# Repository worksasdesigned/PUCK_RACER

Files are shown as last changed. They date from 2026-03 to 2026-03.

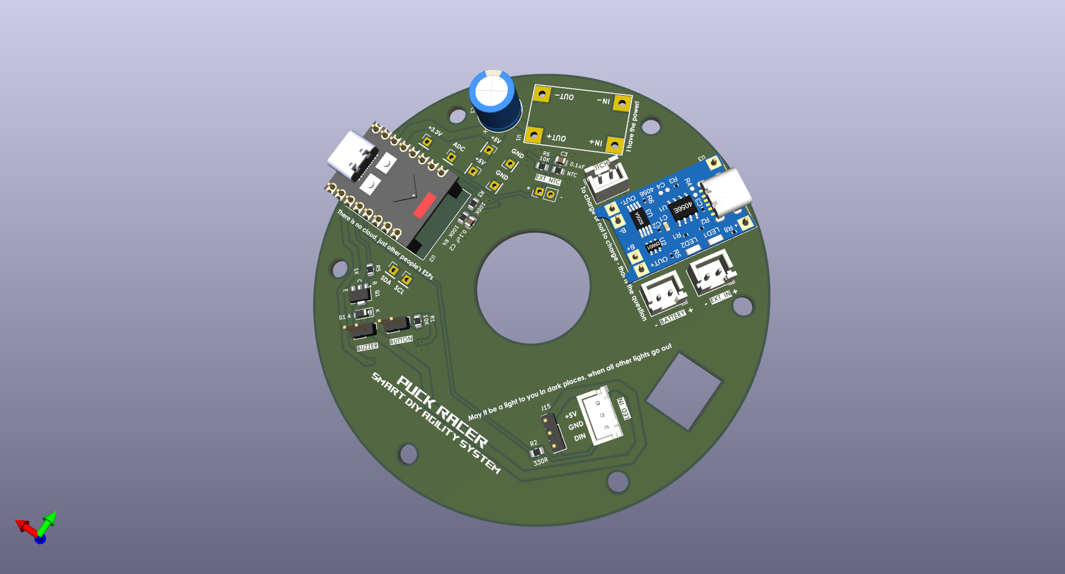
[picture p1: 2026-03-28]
Hardware/PCB Project Outputs/3D Views/Puck Racer_S3.png

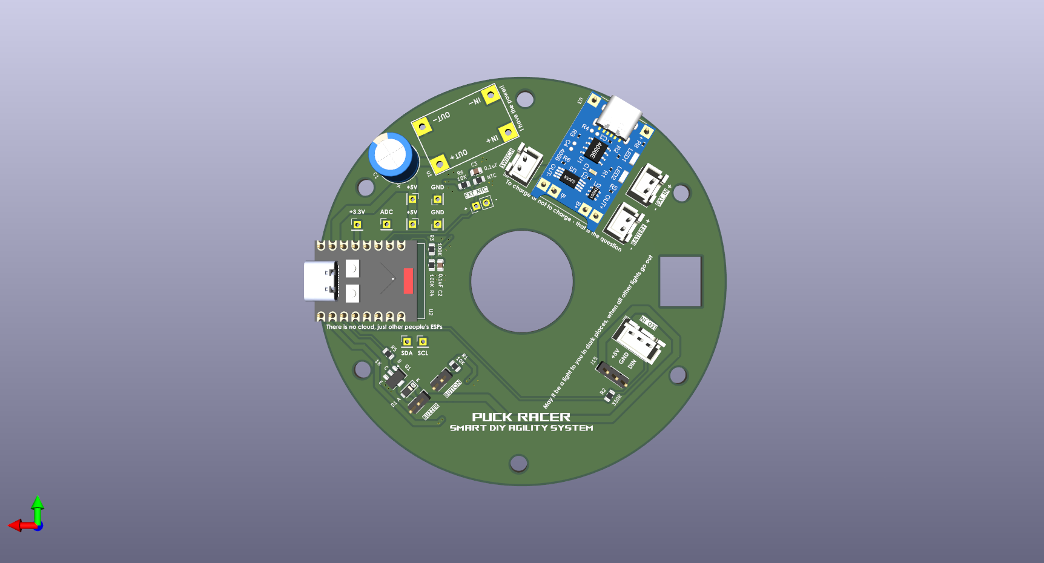
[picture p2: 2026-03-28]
Hardware/PCB Project Outputs/3D Views/Puck Racer_BOTTOM.png

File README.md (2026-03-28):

# Puck Racer 🏃‍♂️💨
**The DIY agility System**

## 📖 The Story: Why this exists
Let's be real for a second: I built this because I was simply too stingy to drop **300-400€** on a commercial reaction light system that consists of only 4 pucks, needs a paid subscription and provides 200 extremely similar games... which can be summerized in 5 different game modes.  
**Puck Racer has now 26 games**. Highly adjustable. Multi-Player, Multi-Group support.  
All options combined easily provide 200+ "games" ;-)  

I also noticed that the PE equipment at my kids' elementary school hasn't really changed in 40 years. It was time for an upgrade.

**Puck Racer** is the answer. It’s perfect for professional training support in sports clubs, spicing up PE lessons in schools, or just being the absolute highlight of the next kids' birthday party.  
I would descibe it as a **blaze**ing**POD** - DIY solution - just on steroids :-)  

**The Trade-off:**
Yes, building 4-10 Pucks and a Coordinator is a bit of a grind. It takes time and patience.

**The Reward:**
You get a fully customizable system where the hardware cost per Puck can be pushed **under 20€**. You do the math. 😉  
Nice side effect: Teach your kids how to solder. Its easy to medium difficulty. My 9 year old twins built 5 pucks by them selfe with very little help.  

---

## 🛠 Hardware
*detailed howto and hardware list will be provided once its worth it*  
ESP32-C3 for pucks   (use the one with external antenna or built a small antenna!)
ESP32-S3 for Coordinator  
WS2812B 35LED ring  
something for 18650 Battery placement + stepup to 5V  
Arcade Button (bigger is better) 60mm  
3D printer for pucks  
Soldering Stuff  
**P A T I E N C E** - printing 10 pucks, soldering 10 times the same stuff and initial flashing needs a good amount of patience.

---

## 💻 Software & Installation

This system relies on a **Coordinator** (ESP32-S3) that acts as the brain and the WiFi Access Point, and multiple **Pucks** (ESP32-C3) that communicate via ESP-NOW.

### 📦 Prerequisites

To compile and flash this project, you need the **Arduino IDE**. Of cause VS Code will also work. 

1.  **ESP32 Board Manager:**
    * Go to *Tools > Board > Boards Manager*.
    * Install **esp32 by Espressif Systems**.
    * **Recommended Version:** `3.0.0` or higher (we need proper S3/C3 support).

2.  **Required Libraries:**
    Install these via the Arduino Library Manager:
    * `FastLED` (for the WS2812B LEDs)
    * `ESPAsyncWebServer from ESPhome project` (for the Coordinator Dashboard)
    * `AsyncTCP from ESPhome project` (dependency for the WebServer)

### 📂 Uploading the Web Interface (IMPORTANT!)

The Coordinator runs a modern Web App stored in the ESP32's internal file system (LittleFS). You **must** upload the files from the `data` folder, otherwise, you'll just see a blank screen.

1.  Download the **Arduino LittleFS Upload Tool**:
    * 👉 [GitHub Link: arduino-littlefs-upload](https://github.com/earlephilhower/arduino-littlefs-upload)
2.  Follow the installation instructions on the repo (copy to `tools` folder).
3.  In Arduino IDE, select the Coordinator board.
4.  Click **Tools > ESP32 LittleFS Data Upload**.

### 📡 Connectivity & OTA Updates

**The Network:**
The Coordinator opens a WiFi Access Point (Default SSID: `PuckRace_Trainer`). Connect your phone or laptop to this network and navigate to `http://192.168.42.1`. No app required, it runs in the browser.  It has no pwassword initially. Your choice to set it up if you deal with kids and their smartphones.

**Wireless Updates (OTA):**
You only need to hook the Pucks up to USB *once* for the initial flash. After that, you're free:
1.  Compile the new Puck firmware (Sketch -> Export Compiled Binary).
2.  Go to the Coordinator Web Interface Settings.
3.  Upload the `.bin` file.
4.  Hit **"Update All Pucks"**. The Coordinator will distribute the update wirelessly to all active Pucks. Magic. ✨

After the real first beta is released il will provide the bin files in case of updates. 

---

## 🎮 The Games

**26 games** across 4 categories. Highly adjustable, multi-player and multi-group support.

| Focus | Icon |
|---|---|
| Hand-eye coordination, fast stimulus processing | ⚡ Reaction |
| Rapid direction changes, sprints, footwork | 🏃‍♂️ Agility |
| Cardiovascular load and pacing | 🫀 Endurance |
| Memory, timing, stress resistance | 🧠 Cognition |
| Teambuilding and motivation | 🤪 Fun |
| Practical tools for coaches and teachers | 🛠️ Utility |

---

### ⚡🏃‍♂️ Agility & Reaction

| Game | Players | Pucks | Focus | Highlights |
|---|---|---|---|---|
| 🎯 **Hunt! (Color Hunt)** | 1–10 | 3–20 | ⚡ 🏃‍♂️ 🧠 | Dynamic queues, adjustable timeout, 1-sec warning |
| ⚡ **React 2-Player** | 2–10 (pairs) | 3–10/group | ⚡ 🧠 | Configurable colors, fake stimuli for confusion |
| 🎯 **Target Touch** | 1–5 groups | 2–10/group | ⚡ 🛠️ | Sequence or random mode, rest time control |
| 🏃‍♂️ **Agility T-Test** | 1–2 groups | 4/group | 🏃‍♂️ | Standard T-test layout, mandatory touch mode |
| 🐱 **Cat Reflex** | 1–11 | 1/player + 1 center | ⚡ | Highlander mode, Color Chaos (false-start training) |
| ⚡🎯 **Catch the light Pro** | 1 | 3–20 | ⚡ 🧠 | Adaptive speed, fake colors, per-puck reaction analysis |

---

### 🫀 Endurance & Pacing

| Game | Players | Pucks | Focus | Highlights |
|---|---|---|---|---|
| ⏱️ **The Pacemaker** | Groups | 4–20 | 🫀 🧠 | Exact pace (min/km), circle or shuttle, live distance |
| 🏃‍♂️ **Luc Léger (Beep Test)** | 1–10 | 2/player | 🫀 | Official VO₂max tables, false start detection |
| 🏃‍♂️ **Shuttle Run** | 1–5 | 2/player | 🏃‍♂️ 🫀 | Winner detection, false start detection |
| 🧟 **Zombie Escape** | 1–10 groups | 2/group | 🫀 🧠 🤪 | Auto time reduction, sudden death mode |
| 🏎️ **Pit Stop** | 1–10 groups | 1-2/group | 🫀 | Making a break. Defined PitStops. Pitlane mode. |

---

### 🧠🤪 Cognition & Fun

| Game | Players | Pucks | Focus | Highlights |
|---|---|---|---|---|
| 🔴 **Simon Says** | 1–3 groups | 2–10/group | 🧠 | Adjustable speed, color-blind palette |
| 🏃‍♂️ **Simon Runs** | 1–3 groups | 1 display + inputs | 🧠 🏃‍♂️ | Central display mode, disqualification management |
| 💣 **Bomb Squad** | 1–10 | 1/player | 🧠 🤪 | Adjustable tolerance, group sync mode, explosion feedback |
| 🚦 **Red Light, Green Light** | 1–10 groups | 1–20 | 🤪 ⚡ | Grace period, coach override |
| 🎩 **The Sorting Hat** | 2–100 | 1–3 | 🛠️ 🤪 | Balanced assignment, live rebalance |
| 🧠 **Memory Sprint** | 1+ | 4–20 (pairs) | 🧠 🏃‍♂️ | Blind search mode, auto-restart, live error tracking |
| ⚔️ **Domination (Turf War)** | 2 teams/arena | 2+/arena | 🏃‍♂️ 🫀 | 1-click vs 2-click capture, dual-arena support |
| ❌⭕ **Tactical TicTacToe** | 1–3 groups | 4 / 6 / 7 / 10 | 🧠 | Hard-Mode, grid auto-adapts to puck count |
| 🪑 **Musical Chairs** | 2–13 | Player count −1 | 🤪 🏃‍♂️ | Custom MP3 upload, dynamic round elimination |

---

### 🛠️ Measurement Tools & Utilities

| Game | Players | Focus | Highlights |
|---|---|---|---|
| ⏱️ **Stopwatch** | 1–10 | 🛠️ | Split/lap times, central or individual start, Hold-to-Start |
| ⏳ **Simple Timer** | 1–10 | 🛠️ | Visual countdown fill, live +/− time adjustment per player |
| 🔢 **Simple Counter** | 1–10 | 🛠️ | Tap-to-count, time limit, debounce filter |
| ⬇️ **Simple Countdown** | 1–10 | 🛠️ | Count down from N, stop-on-winner option |
| 🥵 **TABATA Controller** | Unlimited | 🛠️ 🫀 | Synced progress bars, work/rest phases, configurable sound |
| ▶️ **Display Mode** | — | 🛠️ | Manual/sync/random light control for events |

---

### 👥 Player & Training Manager

| Tool | Description |
|---|---|
| 👥 **Player Manager** | Manage teams and class lists. Upload/backup CSV. Create named groups for quick name assignment. |
| 📋 **Training Manager** | Define training sequences with up to 3 games and pre-set all parameters. Jump between games without touching the setup screens. |

---

## Technical Updates:  

**V2.88.2**  
    - iOS meta Tags added  
    - App Icon added  
    - Check that only 1 device is connected via WiFi  

**V2.89.7**   
    - Simple Statistics added for players maintained in Playermanager  
    - CatReflexes (avarage reaction time)  
    - BombSquad (avarage reaction time)  
    - Shuttle run (time) assuming trainer always uses same distance, else its just a tracking of usage  
    - Countdown (time and clicks) tracking of usage - Fix of copy&paste error in game_simplecounter_setup.html      
**V2.89.13**  
    - statistics for all relevant games finished  
        - Whac-A-Mole  
        - Pacemaker  
        - React2Player  
        - T-Test  
        - Beep Test  
        - Catch the light (incl. System record)  
    - Player manager with extended Export and Import incl. highscores and statistics   
    - Minor bugfixes in some games (Player-List added, minor layout changes)  
        - fix for Whac-A-Mole color picker  
**V2.89.15**   
    - Tutorial adjusted  

**V2.90.12**   
    - RSSI fixed  
    - 12 games small fixes (puck colo) fixed  
    - snall enhancements in various games after Beta Test 1  

**V2.91.1**   
    - new game: Pit Stop  
    - Red Light Green Light small adjustments and fixes  

**V2.92.3**   
    - rename a game to catch the light  
    - Cat Reflex Highlander Mode adjusted  

**V2.93.0**   
    - Bidirectional heartbeat puck firmware 81  

**V2.94.2**   
    - UI 2.0 new design    

**V2.96.1**   
    - Battery Management and auto Power Saving Mode   
    - Toast Message "low Battery level", "shutdown Puck due to critical battery level"   
    - Puck shutdown (deepsleep) at low Battery level (safety)   
    - Puck blocks reboot under 3,6V Battery level (safety)  
    - Max LED Power Consumption reduced to 1.2A (should only effect white @35LEDs) (safety)   
    - Hardware Watchdog implemented (Puck restarts after 3s off non-reactivity)   

**V2.97.1**   
    - Anti-cache links added (Core version behind urls)   
    - _setup.html remembers settings, when navigation back from _run to _names  to _setup.html    

**V2.98.0**   
    - Gerber and PCB files addes   
    - temperature control, warning and local alarm added     

--- 

## 🤝 Contributing
Found a bug? Have a game idea? Feel free to open an issue or submit a pull request. Let's make school sports digital (and affordable)!  
**Licence:** Use it, change it, DO NOT SELL it.  see License.txt

*Project by WorksAsDesigned*

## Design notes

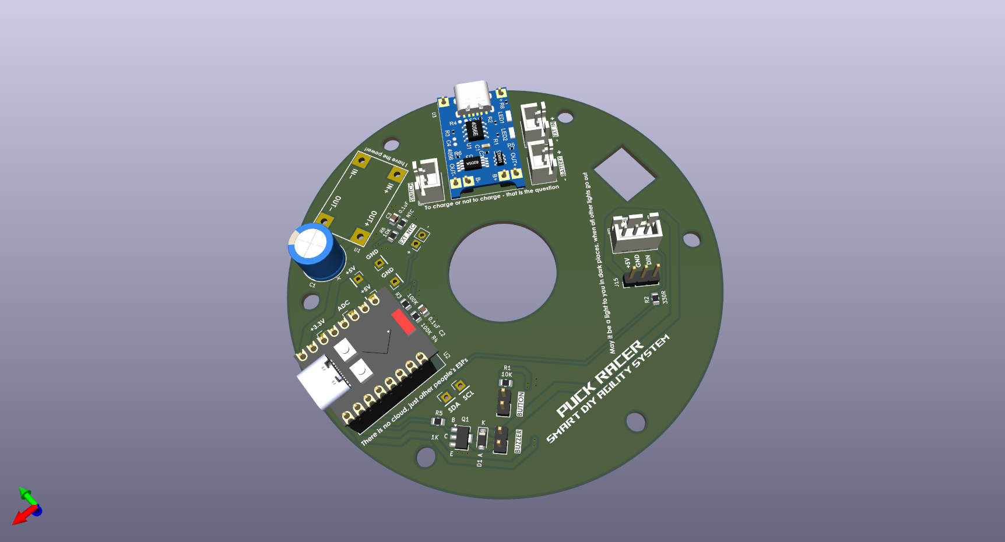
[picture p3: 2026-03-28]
Hardware/PCB Project Outputs/3D Views/Puck Racer_S1.png

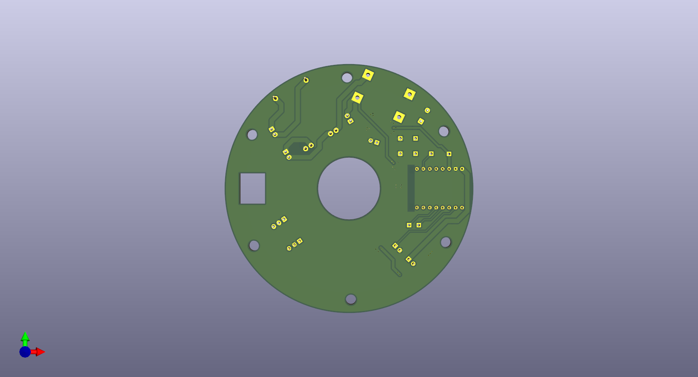
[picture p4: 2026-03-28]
Hardware/PCB Project Outputs/3D Views/Puck Racer_TOP.png

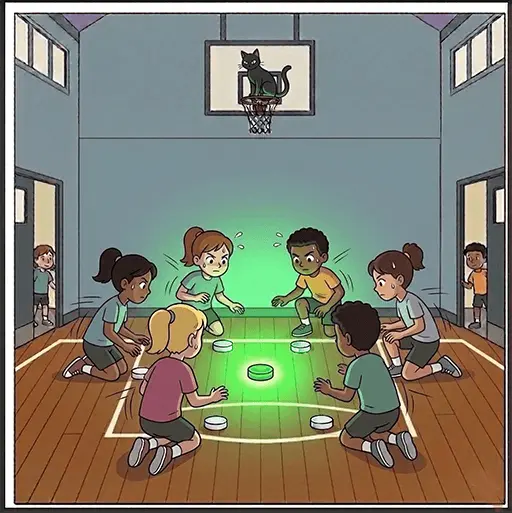
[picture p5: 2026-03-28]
webseite/pictures/img_catreflex.webp

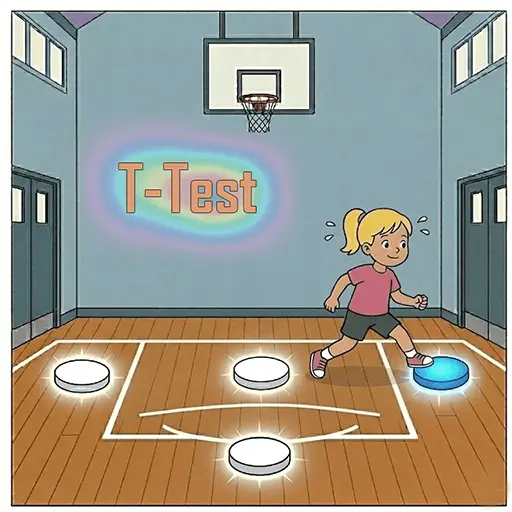
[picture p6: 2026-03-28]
webseite/pictures/img_ttest.webp

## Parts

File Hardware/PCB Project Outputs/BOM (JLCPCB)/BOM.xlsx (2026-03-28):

Comment | Designator | Footprint | JLCPCB Part #
100nF | C2, C3 | Capacitor_SMD:C_0805_2012Metric | C28233
1N4148W | D1 | Diode_SMD:D_SOD-123 | C2099
B2B-XH-A(LF)(SN) | J6, J7, J10 | Connector_JST:JST_XH_B2B-XH-A_1x02_P2.50mm_Vertical | C158012
B3B-XH-A(LF)(SN) | J12 | Connector_JST:JST_XH_B3B-XH-A_1x03_P2.50mm_Vertical | C144394
2N2222AU | Q1 | Package_TO_SOT_SMD:SOT-89-3 | C21714170
10K | R1, R6 | Resistor_SMD:R_0805_2012Metric | C17414
330 | R2 | Resistor_SMD:R_0805_2012Metric | C17630
100K | R3, R4 | Resistor_SMD:R_0805_2012Metric | C25611
1K | R5 | Resistor_SMD:R_0805_2012Metric | C17513
10K NTC | TH1 | Resistor_SMD:R_0805_2012Metric | C95968

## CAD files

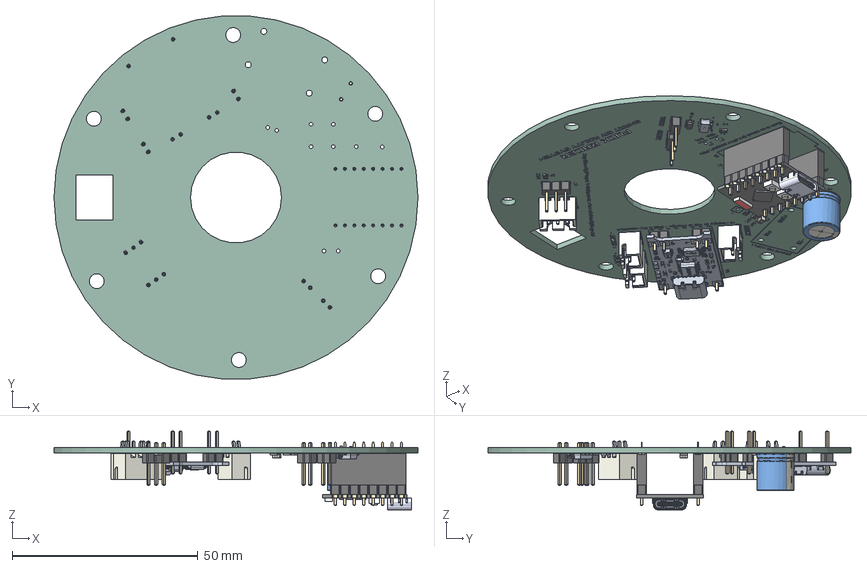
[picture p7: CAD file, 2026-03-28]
Hardware/PCB Project Outputs/STEP/Puck Racer.step
98.0 x 97.7 x 21.2 mm
PinHeader_1x02_P2.54mm_Vertical x 2
R_0805_2012Metric x 7
C_0805_2012Metric x 2
Board c3mini
USB C
components (other)^ESP32-C3 SuperMini
PinHeader_1x08_P2.54mm_Vertical x 2
PinSocket_1x08_P2.54mm_Vertical x 2
JST_XH_B2B-XH-A_1x02_P2.50mm_Vertical x 3
PinHeader_1x01_P2.54mm_Vertical x 6
Puck Racer 1.19.1
Puck Racer 1.19.2
CP_Radial_D10.0mm_P5.00mm
D_SOD-123
JST_XH_B3B-XH-A_1x03_P2.50mm_Vertical
Puck Racer 1.23.1
PinHeader_1x03_P2.54mm_Vertical
Puck Racer_silkscreen
Puck Racer_PCB

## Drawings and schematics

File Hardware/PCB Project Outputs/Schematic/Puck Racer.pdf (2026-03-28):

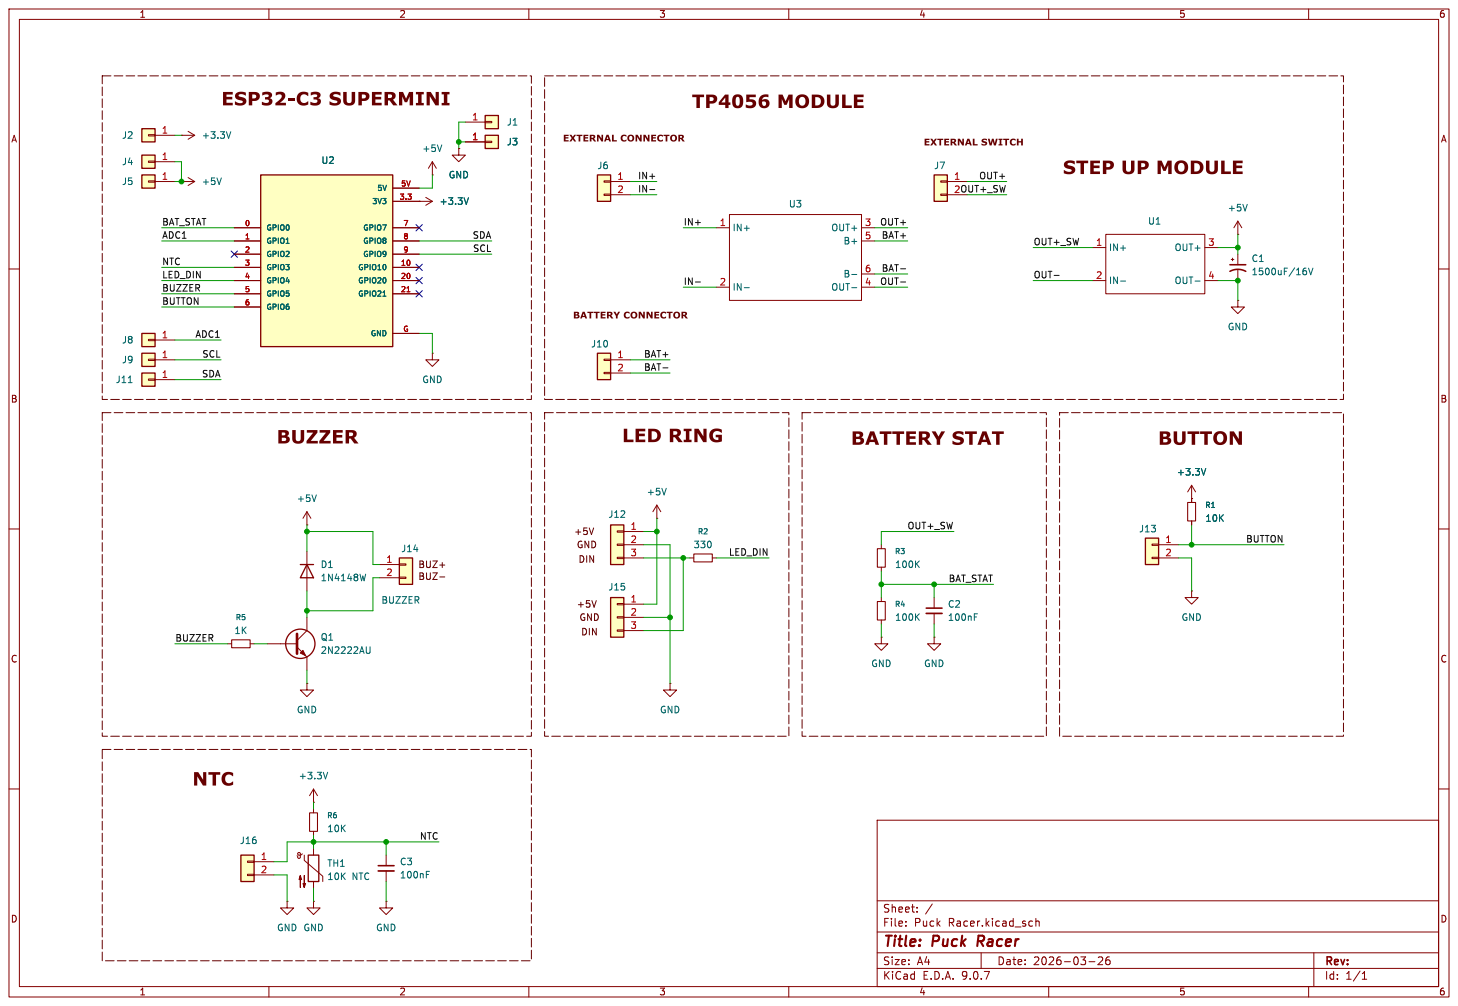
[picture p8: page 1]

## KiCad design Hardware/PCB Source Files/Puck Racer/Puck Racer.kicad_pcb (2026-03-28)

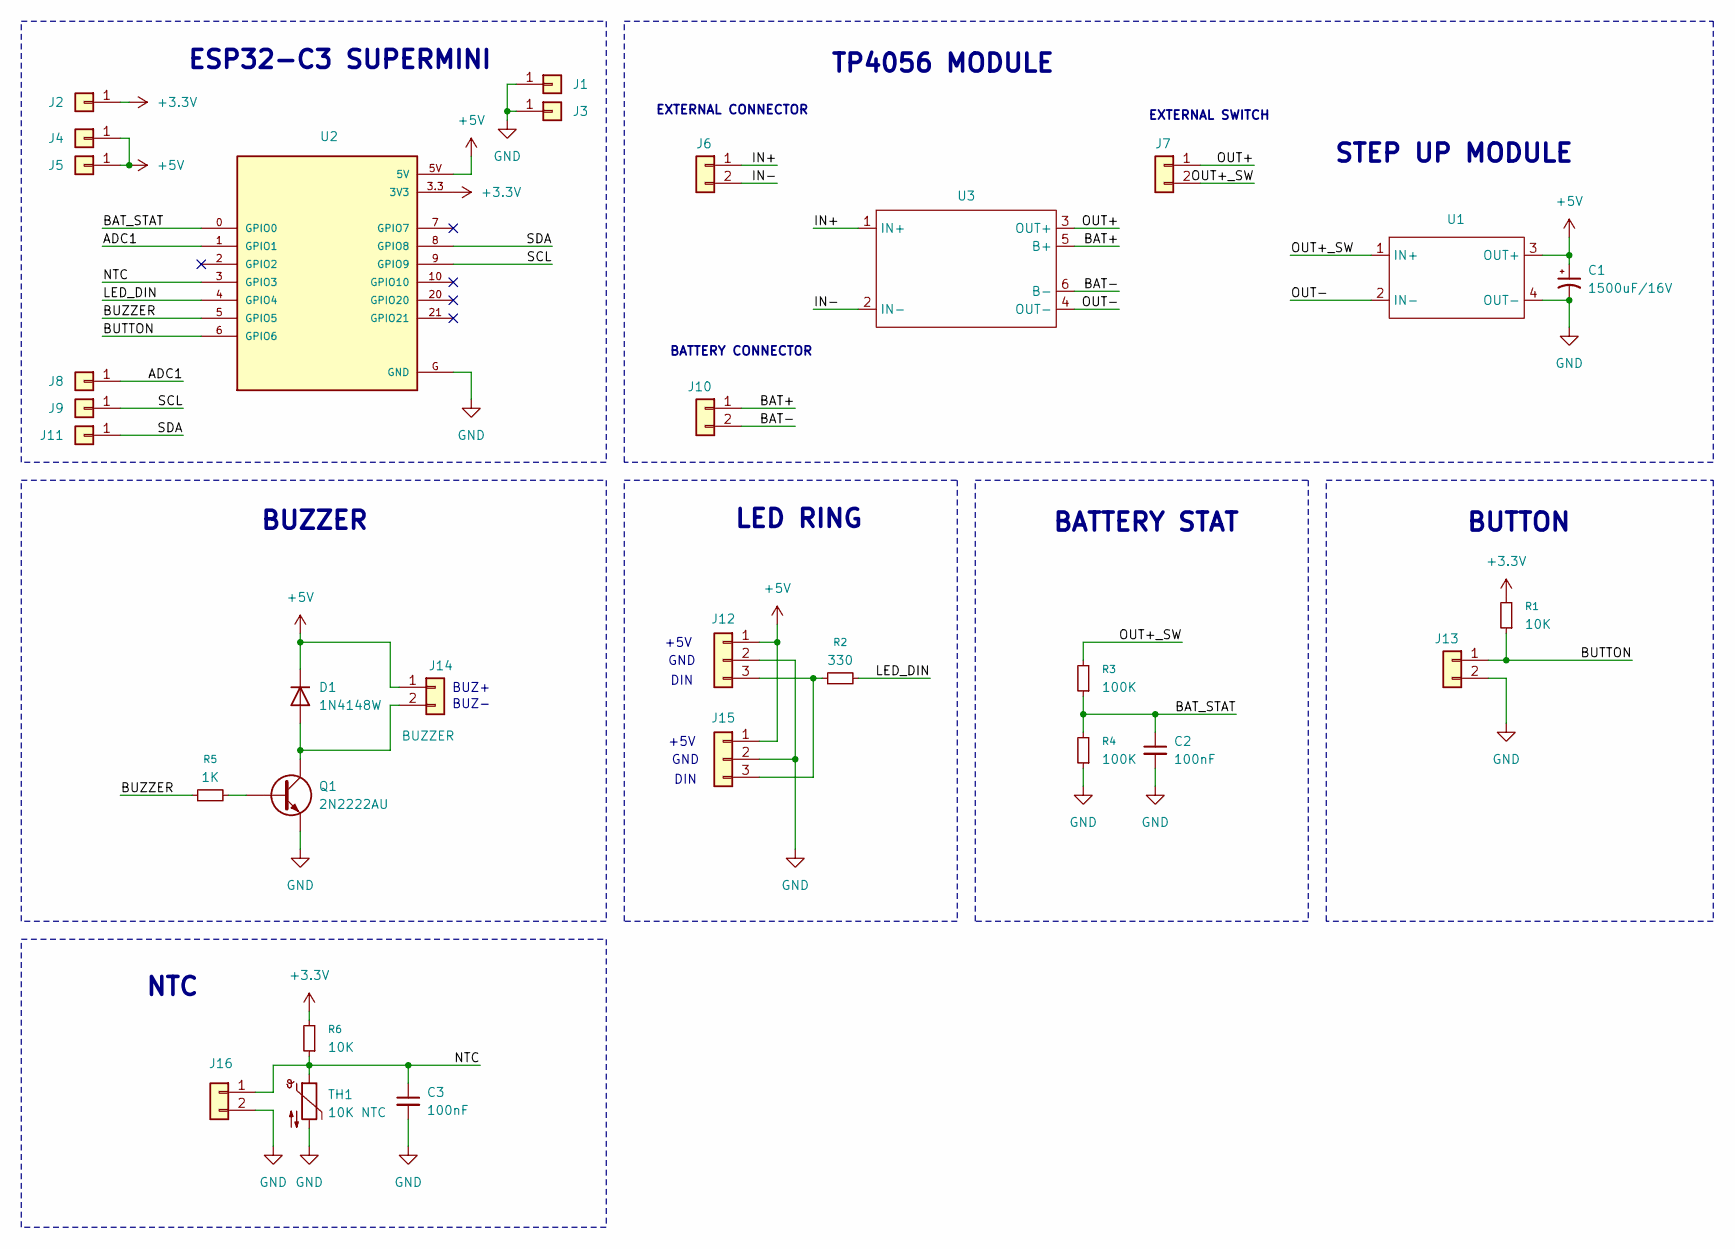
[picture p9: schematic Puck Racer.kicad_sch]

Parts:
C1: 1500uF/16V; CP_Radial_D10.0mm_P5.00mm
C2, C3: 100nF; C_0805_2012Metric; JLCPCB Part # C28233
D1: 1N4148W; D_SOD-123; JLCPCB Part # C2099
J1, J2, J3, J4, J5, J8, J9, J11: Conn_01x01; PinHeader_1x01_P2.54mm_Vertical
J6, J7, J10: B2B-XH-A(LF)(SN); JST_XH_B2B-XH-A_1x02_P2.50mm_Vertical; JLCPCB Part # C158012
J12: B3B-XH-A(LF)(SN); JST_XH_B3B-XH-A_1x03_P2.50mm_Vertical; JLCPCB Part # C144394
J13, J16: BUTTON1; PinHeader_1x02_P2.54mm_Vertical
J14: BUZZER; PinHeader_1x02_P2.54mm_Vertical
J15: LED; PinHeader_1x03_P2.54mm_Vertical
Q1: 2N2222AU; SOT-89-3; JLCPCB Part # C21714170
R1, R6: 10K; R_0805_2012Metric; JLCPCB Part # C17414
R2: 330; R_0805_2012Metric; JLCPCB Part # C17630
R3, R4: 100K; R_0805_2012Metric; JLCPCB Part # C25611
R5: 1K; R_0805_2012Metric; JLCPCB Part # C17513
TH1: 10K NTC; R_0805_2012Metric; JLCPCB Part # C95968
U1: Step Up Power Module
U2: ESP32-C3_SUPERMINI_TH; MODULE_ESP32-C3_SUPERMINI_TH
U3: TP4056 Module

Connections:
+3.3V: J2.1, R1.2, R6.2, U2.3.3 (3V3)
+5V: C1.1, D1.1 (K), J4.1, J5.1, J12.1, J14.1, J15.1, U1.3 (OUT+), U2.5V
/ADC1: J8.1, U2.1 (GPIO1)
/BAT+: J10.1, U3.5 (B+)
/BAT-: J10.2, U3.6 (B-)
/BAT_STAT: C2.1, R3.1, R4.2, U2.0 (GPIO0)
/BUTTON: J13.1, R1.1, U2.6 (GPIO6)
/BUZZER: R5.1, U2.5 (GPIO5)
/IN+: J6.1, U3.1 (IN+)
/IN-: J6.2, U3.2 (IN-)
/LED_DIN: R2.2, U2.4 (GPIO4)
/NTC: C3.1, J16.1, R6.1, TH1.1, U2.3 (GPIO3)
/OUT+: J7.1, U3.3 (OUT+)
/OUT+_SW: J7.2, R3.2, U1.1 (IN+)
/OUT-: U1.2 (IN-), U3.4 (OUT-)
/SCL: J9.1, U2.9 (GPIO9)
/SDA: J11.1, U2.8 (GPIO8)
GND: C1.2, C2.2, C3.2, J1.1, J3.1, J12.2, J13.2, J15.2, J16.2, Q1.3 (E), R4.1, TH1.2, U1.4 (OUT-), U2.G (GND)
unnamed: D1.2 (A), J14.2, Q1.2 (C)
unnamed: J12.3, J15.3, R2.1
unnamed: Q1.1 (B), R5.2

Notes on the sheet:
GND
BUTTON
STEP UP MODULE
BUZZER
DIN
NTC
LED RING
+5V
BUZ+
EXTERNAL CONNECTOR
EXTERNAL SWITCH
BATTERY STAT
BUZ-
TP4056 MODULE
BATTERY CONNECTOR
ESP32-C3 SUPERMINI

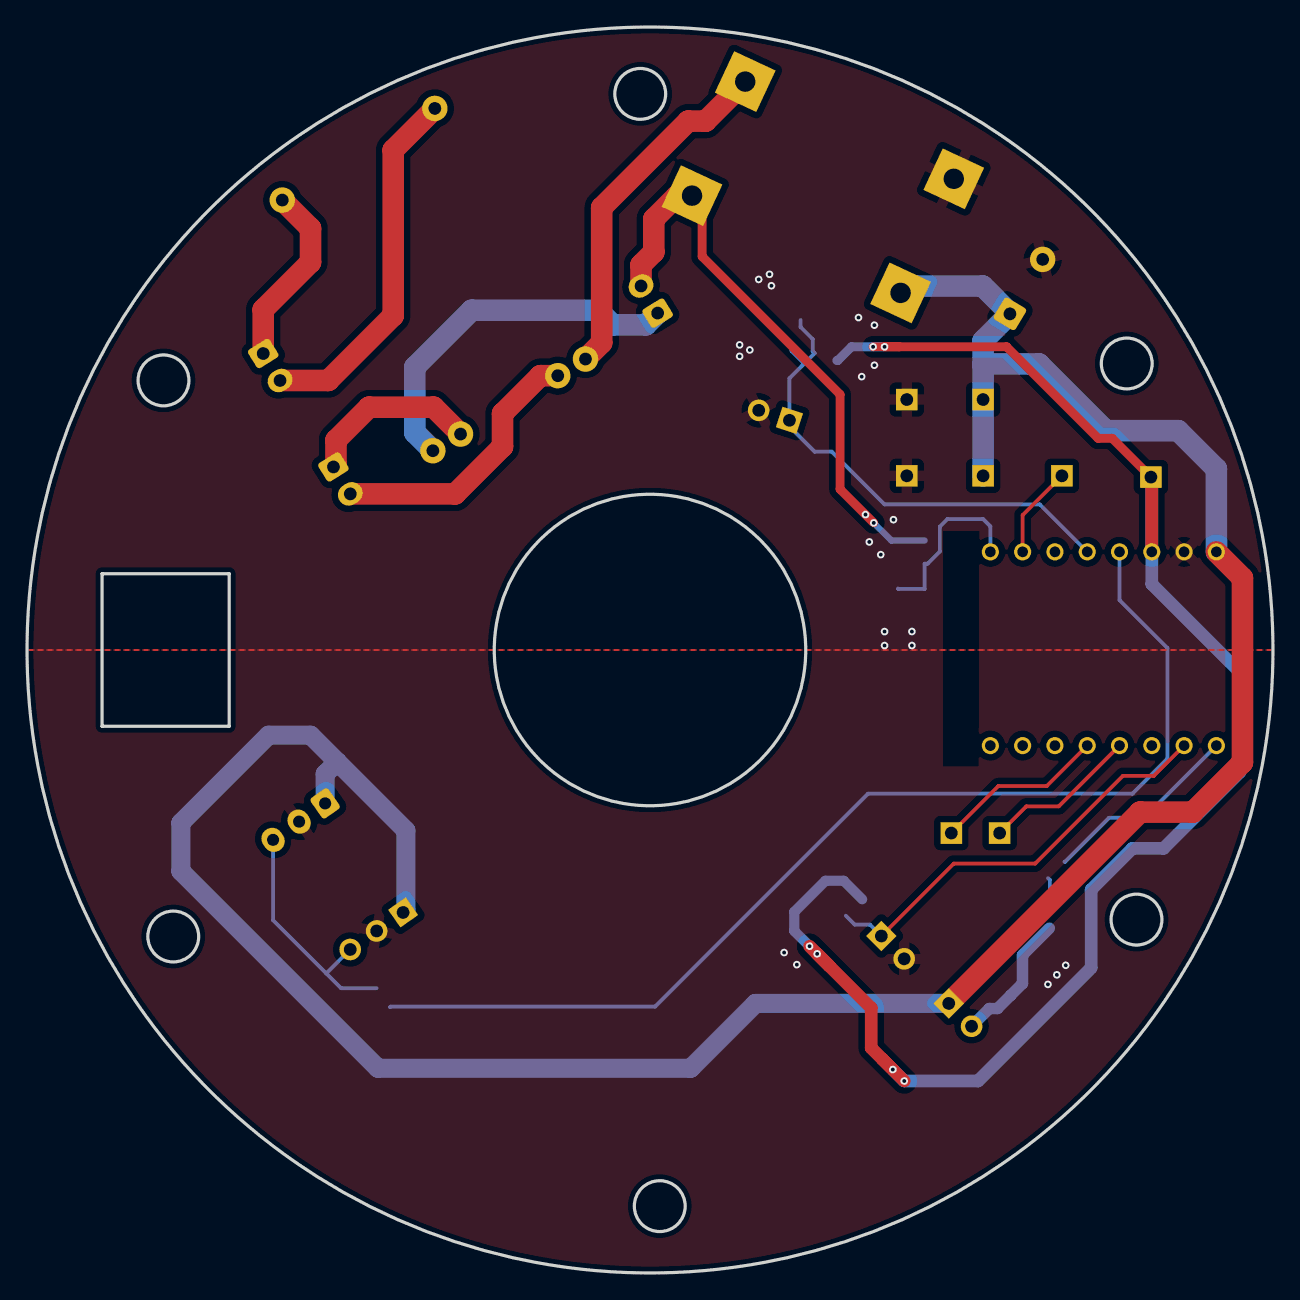
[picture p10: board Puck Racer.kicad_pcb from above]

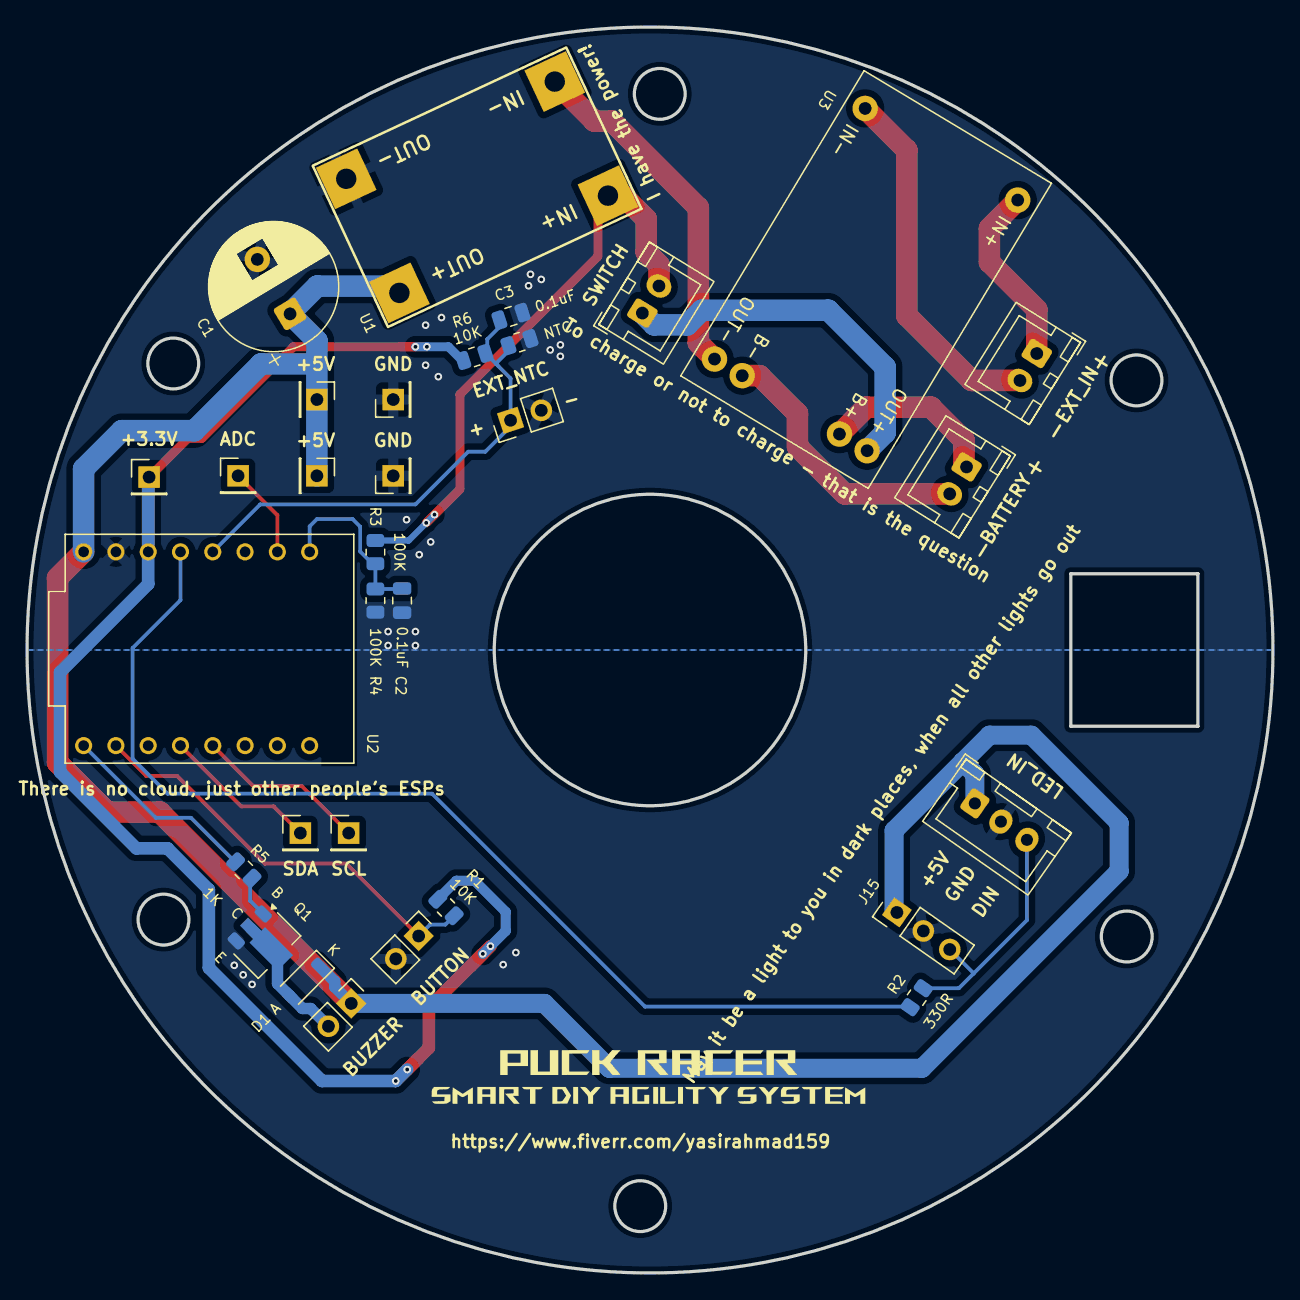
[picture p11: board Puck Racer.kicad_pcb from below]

Board: 2 copper layers, 98.0 x 98.0 mm, 31 parts (31 on the bottom side), 21 nets.

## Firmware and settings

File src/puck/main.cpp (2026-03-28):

/*
 * PROJEKT: Puck Race - PUCK FIRMWARE
 * Version 81 stability fixes, bidirectional heartbeats
 * Version: 80 Battery Update + Sound Fixes + Core 3.x Support
 * VERSION: 75 (FIX: ESP-NOW Core 2.x Kompatibilität + Promiscuous RSSI Sniffer)
 *
 * ÄNDERUNGEN v75:
 * [FIX] esp_now_recv_cb_t Signatur auf Core 2.x Standard angepasst, um
 * Kompilierungsfehler im PlatformIO esp32-c3 Environment zu beheben.
 * [NEW] Promiscuous Sniffer hinzugefügt, um den RSSI-Wert auszulesen,
 * da der Core 2.x ESP-NOW Callback dies nicht nativ unterstützt.
 *
 * ÄNDERUNGEN v73/74:
 * [FIX 1] Race Condition: portMUX_TYPE Spinlock um alle cmdQueue-Zugriffe.
 * [FIX 2] tone() ohne duration-Parameter gegen FreeRTOS Timer Konflikte.
 * [FIX 3] lastReceivedSeq startet bei 255.
 */

#include <Arduino.h>
#include <WiFi.h>
#include <esp_now.h>
#include <esp_wifi.h>
#include <FastLED.h>
#include <HTTPClient.h>
#include <HTTPUpdate.h>
#include <esp_task_wdt.h>
#include <math.h>
#include "Common.h"

// --- HARDWARE ---
#define PIN_BAT     0  // ADC Pin für den Batterie-Spannungsteiler
// GPIO1 ist der letzte freie ADC1-Pin für weitere analoge Sensoren
#define PIN_NTC     3  // NTC Temperatursensor (10kOhm Beta3950, 10kOhm Festwiderstand)
#define PIN_LED     4
#define PIN_BUZZER  5
#define PIN_BTN     6  // Arcade Button (INPUT_PULLUP)
#define NUM_LEDS    35
#define FW_VERSION  85

// --- TEMPERATUR OVERHEAT ---
// Schwellwert in °C – ab diesem Wert wird Overheat-Schutz ausgelöst.
// Zum Feintuning diesen Wert anpassen:
#define TEMP_OVERHEAT_C         60
// NTC Parameter: 10kOhm bei 25°C, Beta 3950, Festwiderstand 10kOhm
#define NTC_R_FIXED             10000.0
#define NTC_R_NOMINAL           10000.0
#define NTC_BETA                3950.0
#define NTC_T_NOMINAL           298.15   // 25°C in Kelvin
#define TEMP_CHECK_INTERVAL_MS  2000
#define OVERHEAT_BEEP_DURATION_MS 30000  // 30 Sekunden aggressives Beepen

// --- BATTERIE ---
#define BAT_CALIBRATION       1.0    // Platzhalter: Feinabstimmung nach Messung (z.B. 1.02)
#define BAT_LOW_BOOT_MV       3700   // Boot-Schwelle: darunter → Notaus
#define BAT_WARNING_MV        3600   // Warnung: darunter → Battery Save (50% Helligkeit)
#define BAT_CRITICAL_MV       3400   // Laufzeit-Schwelle: darunter → Notaus
#define BAT_CHECK_INTERVAL_MS 2000   // Prüfintervall in ms
#define BAT_SAVE_BRIGHTNESS   128    // 50% max Helligkeit im Battery Save Modus

// --- AUDIO NOTEN ---
#define NOTE_B0  31
#define NOTE_C4  262
#define NOTE_D4  294
#define NOTE_E4  330
#define NOTE_F4  349
#define NOTE_G4  392
#define NOTE_A4  440
#define NOTE_B4  494
#define NOTE_C5  523
#define NOTE_D5  587
#define NOTE_E5  659
#define NOTE_G5  784
#define NOTE_A5  880
#define NOTE_B5  988
#define NOTE_C6  1047
#define NOTE_E6  1319

CRGB leds[NUM_LEDS];
const uint8_t broadcastMac[] = BROADCAST_MAC;

// --- STATUS ---
bool isPaired = false;
bool updateRequested = false;
unsigned long lastHeartbeat = 0;
uint8_t coordinatorMac[6] = {0};
bool coordinatorMacKnown = false;
String updateSSID = "";
String updatePW = "";

// STABILITÄTS-FIX: Zeitpunkt des letzten empfangenen Coordinator-Befehls.
// Wird bei jedem eingehenden Kommando (CMD_KEEPALIVE, CMD_EFFECT, etc.) aktualisiert.
// Wenn dieser Wert > 15 Sekunden alt ist, geht der Puck davon aus, dass die
// Verbindung verloren wurde, und wechselt auf roten Status + schnelleres Re-Pairing.
unsigned long lastCommandFromCoordinator = 0;

// --- BATTERIE SCHUTZ ---
bool lowBatteryMode = false;
bool batterySaveMode = false;
unsigned long lastBatteryCheck = 0;
#define BAT_AVG_SAMPLES 5
uint16_t batHistory[BAT_AVG_SAMPLES] = {0};
uint8_t  batHistoryIdx = 0;
uint8_t  batHistoryCount = 0;

// --- TEMPERATUR ---
int16_t currentTemp_c10 = -999;  // Aktuelle Temperatur in 0.1°C, -999 = kein Sensor
unsigned long lastTempCheck = 0;
bool overheatMode = false;
unsigned long overheatStartTime = 0;
unsigned long overheatLastToggle = 0;
bool overheatBuzzerOn = false;

// STABILITÄTS-FIX: Timeout-Schwelle in ms, ab der der Puck die Verbindung
// als verloren betrachtet. Der Coordinator sendet alle 10s einen CMD_KEEPALIVE,
// also sollte bei stabiler Verbindung nie ein 15s-Timeout auftreten.
#define COORDINATOR_TIMEOUT_MS 15000

// GLOBALE RSSI VARIABLE (wird nun vom Sniffer befüllt)
volatile int currentRSSI = 0;

uint8_t globalSeqCounter = 0;
uint8_t lastReceivedSeq = 255;

// --- BEFEHLS-QUEUE (Ringpuffer) ---
#define CMD_QUEUE_SIZE 10
volatile CommandPacket cmdQueue[CMD_QUEUE_SIZE];
volatile int cmdHead = 0;
volatile int cmdTail = 0;

portMUX_TYPE queueMux = portMUX_INITIALIZER_UNLOCKED;

// --- BUTTON (GLITCH FILTER) ---
struct {
    bool state;
    bool lastReading;
    unsigned long lastDebounceTime;
} button = {false, false, 0};

// --- BRIGHTNESS LIMIT ---
uint8_t maxBrightnessPercent = 100;  // Vom Coordinator einstellbar (10-100%)

// --- ANIMATION ENGINE ---
struct {
    uint8_t id = EFF_OFF;
    CRGB color1 = CRGB::Black;
    int speed = 0;
    uint8_t brightness = 50;
    unsigned long lastUpdate = 0;
    int step = 0;
    int counter = 0; 
} anim;

// --- SOUND ENGINE ---
struct Note {
    int freq;
    int duration;
};
#define MAX_SEQ_LEN 30 

struct {
    bool active = false;
    bool isExplosion = false; 
    int seqIndex = 0;
    int seqLength = 0;
    unsigned long nextNoteTime = 0;
    Note currentSeq[MAX_SEQ_LEN];
} sound;

// --- PROTOTYPEN ---
void runAnimation();
void runSound();
void startSoundSequence(uint8_t id);
void setEffect(uint8_t id, uint8_t r, uint8_t g, uint8_t b, int speed, uint8_t bright, uint8_t extra);
void handleButton();
void processIncomingCommands();
void performOTA();
void sendEvent(uint8_t type);

// FIX: Signatur für ESP-NOW Empfang (Unterstützt Core 2.x und 3.x)
#if ESP_IDF_VERSION >= ESP_IDF_VERSION_VAL(5, 0, 0)
void OnDataRecv(const esp_now_recv_info_t * info, const uint8_t *data, int len);
#else
void OnDataRecv(const uint8_t * mac_addr, const uint8_t *data, int len); 
#endif


// =========================================================================
// NEU: RSSI SNIFFER FÜR CORE 2.X
// Belauscht die WLAN Pakete im Hintergrund, um die Signalstärke zu lesen
// =========================================================================
void promiscuous_rx_cb(void *buf, wifi_promiscuous_pkt_type_t type) {
    if (!coordinatorMacKnown) return;
    wifi_promiscuous_pkt_t *pkt = (wifi_promiscuous_pkt_t *)buf;
    if (pkt->rx_ctrl.sig_len >= 24) {
        // Sender-MAC (Offset 10 im 802.11 Header)
        uint8_t *mac = pkt->payload + 10;
        // Nur Pakete vom Coordinator akzeptieren
        if (memcmp(mac, coordinatorMac, 6) == 0) {
            currentRSSI = pkt->rx_ctrl.rssi;
        }
    }
}

uint16_t readBatteryMV() {
    uint32_t adc_mv = analogReadMilliVolts(PIN_BAT);
    return (uint16_t)(adc_mv * 2 * BAT_CALIBRATION);
}

// NTC Temperatur lesen: Spannungsteiler Vcc -> R_fixed -> ADC -> NTC -> GND
// Rückgabe in 0.1°C Einheiten (z.B. 253 = 25.3°C), -999 bei Fehler
int16_t readTemperature() {
    uint32_t adc_mv = analogReadMilliVolts(PIN_NTC);
    if (adc_mv < 10 || adc_mv > 3290) return -999;  // Sensor nicht angeschlossen oder Kurzschluss

    double r_ntc = NTC_R_FIXED * (double)adc_mv / (3300.0 - (double)adc_mv);
    // Steinhart-Hart vereinfacht (Beta-Gleichung):
    // 1/T = 1/T0 + (1/B) * ln(R/R0)
    double steinhart = log(r_ntc / NTC_R_NOMINAL) / NTC_BETA;
    steinhart += 1.0 / NTC_T_NOMINAL;
    double tempK = 1.0 / steinhart;
    double tempC = tempK - 273.15;
    return (int16_t)(tempC * 10.0);
}

void setup() {
    // Buzzer sofort aus (falls Watchdog-Reset während aktivem Ton)
    pinMode(PIN_BUZZER, OUTPUT);
    digitalWrite(PIN_BUZZER, LOW);
    noTone(PIN_BUZZER);

    Serial.begin(115200);

    // Initialisiere ADC Pins (nicht zwingend nötig für analogRead, aber sauberer)
    pinMode(PIN_BAT, INPUT);
    pinMode(PIN_NTC, INPUT);

    pinMode(PIN_BTN, INPUT_PULLUP);
    pinMode(PIN_BUZZER, OUTPUT);
    digitalWrite(PIN_BUZZER, LOW);
    
    FastLED.addLeds<WS2812B, PIN_LED, GRB>(leds, NUM_LEDS);
    FastLED.setBrightness(50);
    FastLED.setMaxPowerInVoltsAndMilliamps(5, 1500); // Sicherheitslimit: max 1,5A bei 5V (real <1A, FastLED schätzt konservativ)

    // --- BATTERIE BOOT-CHECK ---
    {
        uint32_t sum = 0;
        for (int i = 0; i < 8; i++) { sum += readBatteryMV(); delay(5); }
        uint16_t avgMv = sum / 8;
        Serial.printf("Boot battery: %u mV\n", avgMv);
        if (avgMv < 1000) {
            Serial.println("No battery sensor detected – skipping battery protection");
        } else if (avgMv < BAT_CRITICAL_MV) {
            lowBatteryMode = true;
            // Countdown: 35 → 0 LEDs in 1 Sekunde
            for (int n = NUM_LEDS; n >= 0; n--) {
                FastLED.clear();
                for (int j = 0; j < n; j++) leds[j] = CRGB::Red;
                FastLED.show();
                delay(1000 / (NUM_LEDS + 1));
            }
            // 2x rot blinken
            for (int b = 0; b < 2; b++) {
                fill_solid(leds, NUM_LEDS, CRGB::Red); FastLED.show(); delay(150);
                FastLED.clear(); FastLED.show(); delay(150);
            }
            Serial.println("LOW BATTERY MODE at boot!");
        } else if (avgMv < BAT_LOW_BOOT_MV) {
            batterySaveMode = true;
            Serial.printf("Battery Save Mode at boot (%u mV)\n", avgMv);
        }
    }

    if (!lowBatteryMode) startSoundSequence(SEQ_MARIO);

    // WATCHDOG: 3s Timeout, automatischer Reboot bei Hänger
    esp_task_wdt_config_t wdt_config = {
        .timeout_ms = 3000,
        .idle_core_mask = 0,
        .trigger_panic = true
    };
    esp_task_wdt_init(&wdt_config);
    esp_task_wdt_add(NULL);

    // WIFI SETUP
    WiFi.mode(WIFI_STA); 
    WiFi.disconnect();
    
    // RSSI Sniffer: Callback registrieren, aber standardmäßig DEAKTIVIERT lassen.
    // -------------------------------------------------------------------------
    // STABILITÄTS-FIX: Der Promiscuous Mode war bisher permanent aktiv. Das bedeutet,
    // dass JEDES WiFi-Paket in der Luft (auch von fremden Netzwerken, Handys, etc.)
    // einen ISR-Callback auf dem Puck auslöst. Bei 4 Pucks in einer WiFi-dichten
    // Umgebung erzeugt das erhebliche CPU-Last und kann dazu führen, dass ESP-NOW
    // Pakete (Heartbeats, Button-Events) verloren gehen.
    //
    // Der Sniffer wird jetzt nur noch aktiviert, wenn EFF_STATUS gesetzt wird
    // (dort wird currentRSSI für die Rot/Grün-Anzeige gebraucht), und bei allen
    // anderen Effekten wieder deaktiviert. Siehe setEffect().
    esp_wifi_set_promiscuous_rx_cb(&promiscuous_rx_cb);
    esp_wifi_set_channel(WIFI_CHANNEL, WIFI_SECOND_CHAN_NONE);
    esp_wifi_set_promiscuous(false); // Standardmäßig AUS → weniger CPU-Last

    if (esp_now_init() != ESP_OK) ESP.restart();
    esp_now_register_recv_cb(OnDataRecv);
    
    esp_now_peer_info_t peerInfo = {};
    memcpy(peerInfo.peer_addr, broadcastMac, 6);
    peerInfo.channel = WIFI_CHANNEL; 
    peerInfo.encrypt = false;
    esp_now_add_peer(&peerInfo);

    button.state = (digitalRead(PIN_BTN) == LOW);
    button.lastReading = button.state;
    button.lastDebounceTime = millis();
}

void loop() {
    esp_task_wdt_reset();
    if (updateRequested) { performOTA(); return; }
    
    if (cmdHead != cmdTail) { processIncomingCommands(); }

    handleButton();
    runAnimation();
    runSound(); 

    unsigned long now = millis();

    // --- RUNTIME LOW BATTERY CHECK (alle 2s, Entscheidung nach 5 Messungen = 10s Mittelwert) ---
    if (!lowBatteryMode && now - lastBatteryCheck >= BAT_CHECK_INTERVAL_MS) {
        lastBatteryCheck = now;
        uint16_t batNow = readBatteryMV();

        // Ringpuffer befüllen
        batHistory[batHistoryIdx] = batNow;
        batHistoryIdx = (batHistoryIdx + 1) % BAT_AVG_SAMPLES;
        if (batHistoryCount < BAT_AVG_SAMPLES) batHistoryCount++;

        // Erst auswerten wenn Puffer voll (5 Messungen = 10s)
        if (batHistoryCount >= BAT_AVG_SAMPLES) {
            uint32_t sum = 0;
            for (uint8_t i = 0; i < BAT_AVG_SAMPLES; i++) sum += batHistory[i];
            uint16_t batAvg = sum / BAT_AVG_SAMPLES;

            if (batAvg >= 1000 && batAvg <= BAT_CRITICAL_MV) {
                Serial.printf("CRITICAL: Battery avg %u mV → lowBatteryMode!\n", batAvg);
                noTone(PIN_BUZZER);
                sound.active = false;
                // Countdown-Animation VOR dem Sperren zeigen
                FastLED.setBrightness(200);
                for (int n = NUM_LEDS; n >= 0; n--) {
                    FastLED.clear();
                    for (int j = 0; j < n; j++) leds[j] = CRGB::Red;
                    FastLED.show();
                    delay(1000 / (NUM_LEDS + 1));
                }
                for (int b = 0; b < 2; b++) {
                    fill_solid(leds, NUM_LEDS, CRGB::Red); FastLED.show(); delay(150);
                    FastLED.clear(); FastLED.show(); delay(150);
                }
                // Jetzt sperren
                lowBatteryMode = true;
                anim.id = EFF_OFF;
            } else if (batAvg >= 1000 && batAvg <= BAT_WARNING_MV && !batterySaveMode) {
                batterySaveMode = true;
                Serial.printf("WARNING: Battery avg %u mV → batterySaveMode (50%% brightness)\n", batAvg);
                FastLED.setBrightness(min(anim.brightness, (uint8_t)BAT_SAVE_BRIGHTNESS));
            }
        }
    }

    // --- TEMPERATUR CHECK & OVERHEAT SCHUTZ ---
    if (now - lastTempCheck >= TEMP_CHECK_INTERVAL_MS) {
        lastTempCheck = now;
        currentTemp_c10 = readTemperature();

        if (!overheatMode && currentTemp_c10 != -999 && currentTemp_c10 >= TEMP_OVERHEAT_C * 10) {
            overheatMode = true;
            overheatStartTime = now;
            overheatLastToggle = now;
            overheatBuzzerOn = false;
            // LED Ring aus
            setEffect(EFF_OFF, 0, 0, 0, 0, 0, 0);
            Serial.printf("OVERHEAT: %d.%d°C >= %d°C → Overheat-Schutz aktiv!\n",
                          currentTemp_c10 / 10, abs(currentTemp_c10 % 10), TEMP_OVERHEAT_C);
        }
    }

    // Overheat Beep-Sequenz: aggressives AN/AUS für 30 Sekunden
    if (overheatMode) {
        if (now - overheatStartTime < OVERHEAT_BEEP_DURATION_MS) {
            // 250ms AN, 250ms AUS → aggressives Beepen
            if (now - overheatLastToggle >= 250) {
                overheatLastToggle = now;
                overheatBuzzerOn = !overheatBuzzerOn;
                if (overheatBuzzerOn) tone(PIN_BUZZER, 2000);
                else noTone(PIN_BUZZER);
            }
            // LED Ring bleibt aus, alle anderen Effekte blockieren
            if (anim.id != EFF_OFF) setEffect(EFF_OFF, 0, 0, 0, 0, 0, 0);
        } else {
            // 30 Sekunden vorbei → Buzzer aus, Overheat bleibt aber aktiv
            noTone(PIN_BUZZER);
            overheatBuzzerOn = false;
            // Prüfe ob Temperatur wieder unter Schwelle (mit 5°C Hysterese)
            if (currentTemp_c10 != -999 && currentTemp_c10 < (TEMP_OVERHEAT_C - 5) * 10) {
                overheatMode = false;
                Serial.println("OVERHEAT: Temperatur normalisiert – Schutz deaktiviert.");
            }
        }
    }

    // =========================================================================
    // DISCONNECT-ERKENNUNG: Coordinator → Puck Verbindungsüberwachung
    // =========================================================================
    // Der Coordinator sendet alle 10s einen CMD_KEEPALIVE Broadcast.
    // Wenn wir seit COORDINATOR_TIMEOUT_MS (15s) keinen einzigen Befehl mehr
    // empfangen haben, ist die Verbindung sehr wahrscheinlich unterbrochen.
    //
    // Reaktion:
    //   1. LED auf ROT setzen → visuelles Feedback für den Benutzer
    //   2. isPaired = false → Puck sendet jetzt alle 2s EVT_HELLO statt
    //      alle 5s EVT_HEARTBEAT, was das Re-Pairing beschleunigt
    //   3. Promiscuous Sniffer deaktivieren → CPU-Last reduzieren
    //
    // lastCommandFromCoordinator == 0 bedeutet: noch nie ein Befehl empfangen
    // (Startup-Phase), dann wird kein Timeout ausgelöst.
    if (isPaired && lastCommandFromCoordinator > 0 &&
        now - lastCommandFromCoordinator > COORDINATOR_TIMEOUT_MS) {

        Serial.printf("DISCONNECT: Kein Coordinator-Signal seit %lums → Verbindung verloren!\n",
                      now - lastCommandFromCoordinator);
        isPaired = false;
        coordinatorMacKnown = false;
        lastHeartbeat = 0;  // Sofort EVT_HELLO senden beim nächsten Loop-Durchlauf

        // Visuelles Feedback: Status-LED auf ROT
        setEffect(EFF_STATUS, 255, 0, 0, 0, 255, 0);

        // Sniffer aus (spart CPU während der Reconnect-Phase)
        esp_wifi_set_promiscuous(false);
    }

    if (!isPaired) {
        if (now - lastHeartbeat > 2000) {
            sendEvent(EVT_HELLO);
            lastHeartbeat = now;
        }
    } else {
        if (now - lastHeartbeat > 5000) {
            sendEvent(EVT_HEARTBEAT);
            lastHeartbeat = now;
        }
    }
}

void runSound() {
    if (!sound.active) return;
    unsigned long now = millis();

    if (sound.isExplosion) {
        if (now >= sound.nextNoteTime) {
            if (sound.seqIndex++ < 100) { 
                tone(PIN_BUZZER, random(50, 400)); 
                sound.nextNoteTime = now + 5; 
            } else {
                noTone(PIN_BUZZER); 
                sound.active = false;
            }
        }
        return;
    }

    if (now >= sound.nextNoteTime) {
        if (sound.seqIndex < sound.seqLength) {
            int f = sound.currentSeq[sound.seqIndex].freq;
            int d = sound.currentSeq[sound.seqIndex].duration;
            
            if (f > 0) tone(PIN_BUZZER, f); 
            else noTone(PIN_BUZZER);
            
            sound.nextNoteTime = now + d + 20; 
            sound.seqIndex++;
        } else {
            noTone(PIN_BUZZER); 
            sound.active = false;
        }
    }
}

void addNote(int freq, int dur) {
    if(sound.seqLength < MAX_SEQ_LEN) {
        sound.currentSeq[sound.seqLength].freq = freq;
        sound.currentSeq[sound.seqLength].duration = dur;
        sound.seqLength++;
    }
}

void startSoundSequence(uint8_t id) {
    if (lowBatteryMode) { noTone(PIN_BUZZER); sound.active = false; return; }
    noTone(PIN_BUZZER);
    sound.active = true;
    sound.isExplosion = false;
    sound.seqIndex = 0;
    sound.seqLength = 0;
    sound.nextNoteTime = millis();

    switch(id) {
        case SEQ_OFF:
            sound.active = false;
            noTone(PIN_BUZZER);
            return; 
        case SEQ_FANFARE: 
            addNote(NOTE_C5, 100); addNote(NOTE_E5, 100); addNote(NOTE_G5, 100);
            addNote(0, 50); addNote(NOTE_C6, 400);
            break;
        case SEQ_ERROR: 
            addNote(NOTE_G4, 400);
            break;
        case SEQ_EXPLOSION:
            sound.isExplosion = true;
            break;
        case SEQ_HERO: 
            addNote(NOTE_C4, 200); addNote(NOTE_G4, 200); addNote(NOTE_C5, 600);
            break;
        case SEQ_MARIO: 
            addNote(NOTE_E5, 100); addNote(0, 50); addNote(NOTE_E5, 100); 
            addNote(0, 100); addNote(NOTE_E5, 100); addNote(0, 100);
            addNote(NOTE_C5, 100); addNote(NOTE_E5, 100);
            break;
        case SEQ_RACE: 
            addNote(NOTE_C4, 400); addNote(0, 400); 
            addNote(NOTE_C4, 400); addNote(0, 400); 
            addNote(NOTE_C5, 800); 
            break;
        case SEQ_SKI: 
            addNote(600, 100); addNote(0, 900);
            addNote(600, 100); addNote(0, 900);
            addNote(600, 100); addNote(0, 900);
            addNote(1200, 800);
            break;
        case SEQ_DINGDONG:
            addNote(NOTE_E5, 150); addNote(NOTE_C6, 400);
            break;
        case SEQ_TETRIS:
            addNote(NOTE_E5, 120); addNote(NOTE_B4, 60);  addNote(NOTE_C5, 60);
            addNote(NOTE_D5, 120); addNote(NOTE_C5, 60);  addNote(NOTE_B4, 60);
            addNote(NOTE_A4, 120); addNote(NOTE_A4, 60);  addNote(NOTE_C5, 60);
            addNote(NOTE_E5, 120); addNote(NOTE_D5, 60);  addNote(NOTE_C5, 60);
            addNote(NOTE_B4, 180); addNote(NOTE_C5, 60);  addNote(NOTE_D5, 120);
            addNote(NOTE_E5, 120); addNote(NOTE_C5, 120); addNote(NOTE_A4, 120);
            break;
    }
}
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

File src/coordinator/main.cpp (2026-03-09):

/*
 * PROJEKT: Puck Race - COORDINATOR (S3)
 * IP: 192.168.42.1 | SSID: PuckRace_Trainer (No PW)
 * printStats() gibt info über pakete (wenn man auf die settings.html geht) einfach im Serialen console eingeben
 */

#include <Arduino.h>
#include <WiFi.h>
#include <esp_now.h>
#include <LittleFS.h>
#include "Common.h"
#include "WebHandler.h"
#include "GameManager.h"
#include "PuckNetwork.h" 
#include "WifiScanner.h"

#define SYSTEM_VERSION "1.6-Debug"

void setup() {
    Serial.begin(115200);
    delay(2000); // Warten damit man den Serial Monitor öffnen kann
    Serial.println("\n\n--- COORDINATOR BOOT ---");

    // 1. Dateisystem
    if (!LittleFS.begin(true)) {
        Serial.println("FATAL: LittleFS Mount Fail");
        return;
    }
    
    // --- SPEICHER CHECK ---
    size_t total = LittleFS.totalBytes();
    size_t used = LittleFS.usedBytes();
    Serial.printf("LittleFS Total: %u Bytes\n", total);
    Serial.printf("LittleFS Used:  %u Bytes\n", used);
    Serial.printf("LittleFS Free:  %u Bytes\n", total - used);
    
    if ((total - used) < 300000) { // Warnung bei weniger als 300kb
        Serial.println("!!! ACHTUNG: Speicher fast voll! Uploads könnten fehlschlagen !!!");
    }
    // ----------------------

    // 2. Netzwerk Start
    PuckNetwork::begin(); 

    // 3. Webserver Start
    WebHandler::begin();

    // 4. Game Engine Start
    GameManager::begin();

    Serial.println("System Bereit. IP: 192.168.42.1");
}

void loop() {
    PuckNetwork::update(); 
    WebHandler::update();      
    GameManager::update();  
    WifiScanner::loop();   
}

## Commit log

2026-03-10 Only 1 device is allowed to be connected via webinterface
2026-03-10 Statistik SimonSays und shuttle run, bugfix simon says_run
    [Game_SimonSays.cpp]
2026-03-12 Countdown_setup fix, Statistik in catreflexes, Bomb und Countdown
    [Game_CatReflex.cpp]
2026-03-13 V2.89.12 Fix Whac-A-Mole
    [S_320.csv, s_317.csv, s_318.csv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]
2026-03-16 V2.90.1 RSSI, Shuttlerun fix, Board Version 3.x/2.x mix
    [Game_ShuttleRun.cpp, main.cpp]
2026-03-16 V2.90.8 sorting hat last group assignment not shown bug fixed
    [Game_SortingHat.cpp]
2026-03-16 V2.90.10 react2P individual group timer
2026-03-16 V2.90.10 timer fix
2026-03-18 V2.90.12 only1device fix, small fix in simple timer
2026-03-20 V2.91.2 NEW Pitstop, redgreen bugfix
    [GameManager.cpp, StatsManager.cpp]
2026-03-21 V2.92.1 bugfix Hunt, new Deathmatch mode in Domination
    [Game_Domination.cpp]
2026-03-21 V2.92.3 Rename a game to Catch the light, fix CatReflex Highlander mode
    [GameManager.cpp, Game_CatReflex.cpp, Game_CatReflex.h]
2026-03-21 V2.93.0 bidirectional heartbeat, no powersaving , network stability
    [PuckNetwork.cpp, main.cpp]
2026-03-23 V2.94.3 tutorial fix, statistic example / translation
    [s_317.csv]
2026-03-23 V82 HardwareWatchdog, max LED power consumption 1.2A@5V
2026-03-23 V2.95.1 / V82 small bugfixes HWD & pitstop
    [main.cpp]
2026-03-23 V2.96.1 / V83 improved battery warning, RSSI sniffer checks MAC of Coordinator
2026-03-24 V2.96.1 Battery Management
2026-03-24 V2.97.3 General mute button added
2026-03-25 V2.97.7 total play time, settings translated, timer default britness 33%
2026-03-25 V2.97.7 Variable battery warning, timer brightness adjusted to 33%
2026-03-28 V2.98.0 Thermal control of Puck inside, Warning, shutdown. Hardware files Added for PCB
    [BOM.xlsx, Puck Racer.kicad_pcb, Puck Racer.kicad_sch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]
2026-03-28 V2.98.0 UI update, temp control, website, new settings page, battery warning
